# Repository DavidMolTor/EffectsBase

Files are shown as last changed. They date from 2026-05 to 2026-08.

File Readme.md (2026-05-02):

# EFFECTS BASE

Guitar effects platform for interfacing with mini PCIe based boards.

## Introduction

This project consists of a platform with all the controls and signal management for mini PCIe board-based guitar effects.

The platform contains a total of 4 potentiometers and 4 SPDT switches that are accessible throught he mini PCIe connector.

For powering, it offers high filtering and a charge pump in order to produce a negative supply rail.

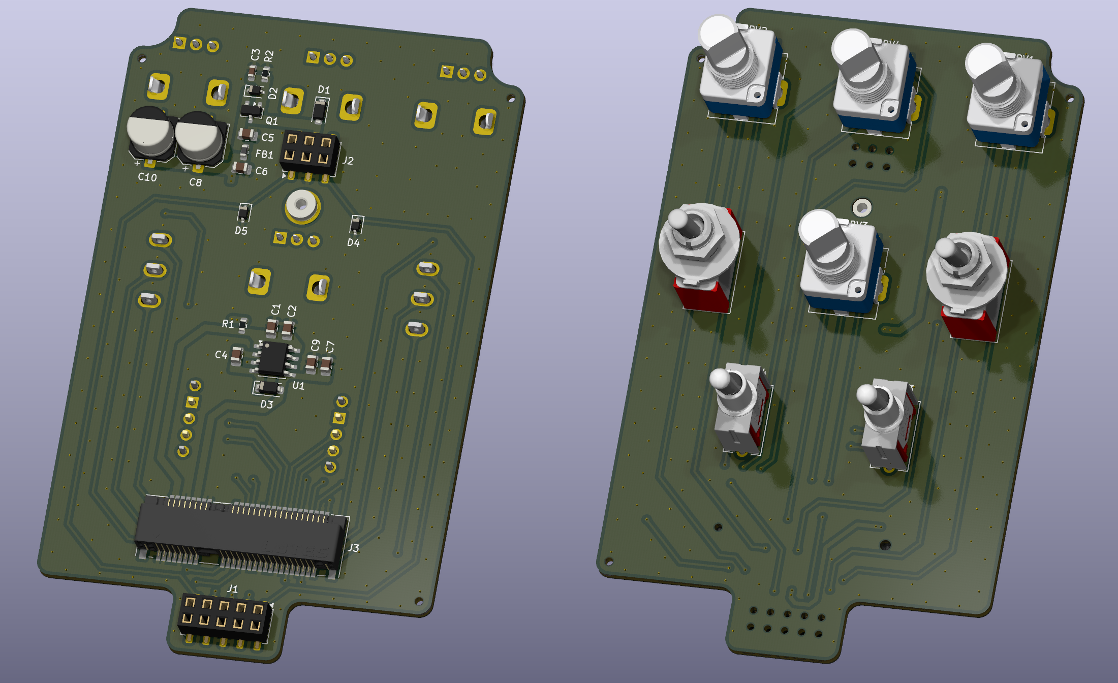
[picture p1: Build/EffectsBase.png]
EFFECTS BASE


## Features

 - Mini PCIe connector

- Charge pump inverter

 - 4 potentiometers

 - 4 SPDT switches

 - True bypass

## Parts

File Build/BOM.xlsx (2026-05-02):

Reference | Value | Footprint | Qty | Manufacturer Part | JLCPCB Part
C1,C2,C4,C5,C6,C7,C9 | 10u | Capacitor_SMD:C_0805_2012Metric | 7 | CL21A106KAYNNNE | C15850
C3 | 10n | Capacitor_SMD:C_0603_1608Metric | 1 | 0603B103K500NT | C57112
D1 | SMF10CA | Diode_SMD:D_SOD-123F | 1 | SMF10CA | C19077505
D2 | MMSZ5248B | Diode_SMD:D_SOD-323 | 1 | MMSZ5248BS | C22395566
D3 | B5819W | Diode_SMD:D_SOD-123 | 1 | B5819W SL | C8598
D4,D5 | H15VSD3B | Diode_SMD:D_SOD-323 | 2 | H15VSD3B | C20615814
FB1 | 850 | Inductor_SMD:L_0603_1608Metric | 1 | SDCL1608C68NJTDF | C13415
J3 | PCIE_FX | Custom_Parts:Mini PCI_Express_Pads | 1 | 91304-99-052R2 | C404126
Q1 | SI2301BDS | Package_TO_SOT_SMD:SOT-23 | 1 | SI2301CDS-T1-GE3 | C10487
R1 | 100 | Resistor_SMD:R_0603_1608Metric | 1 | 0603WAF1000T5E | C22775
R2 | 4.7K | Resistor_SMD:R_0603_1608Metric | 1 | 0603WAF4701T5E | C23162
U1 | ICL7660S | Package_SO:SOIC-8_3.9x4.9mm_P1.27mm | 1 | ICL7660SIBAZT | C7535

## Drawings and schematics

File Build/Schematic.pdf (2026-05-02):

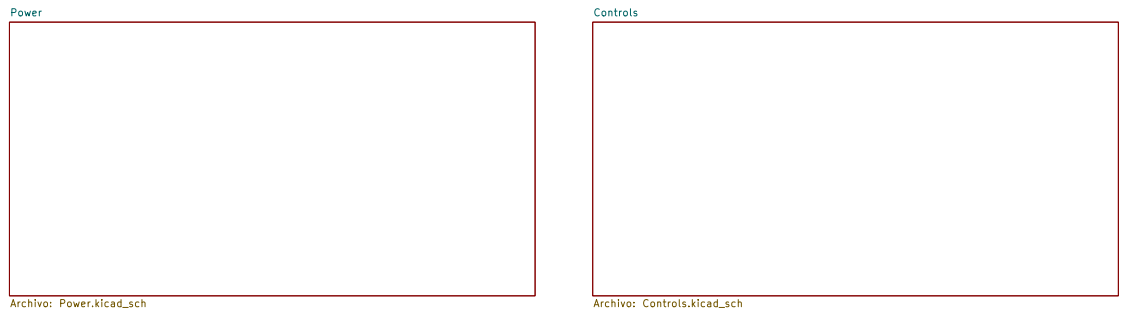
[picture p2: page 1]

Controls Archivo: Controls.kicad_sch Power Archivo: Power.kicad_sch

Size: A4 | Rev: 1.0
KiCad E.D.A. 10.0.1 | Id: 1/3

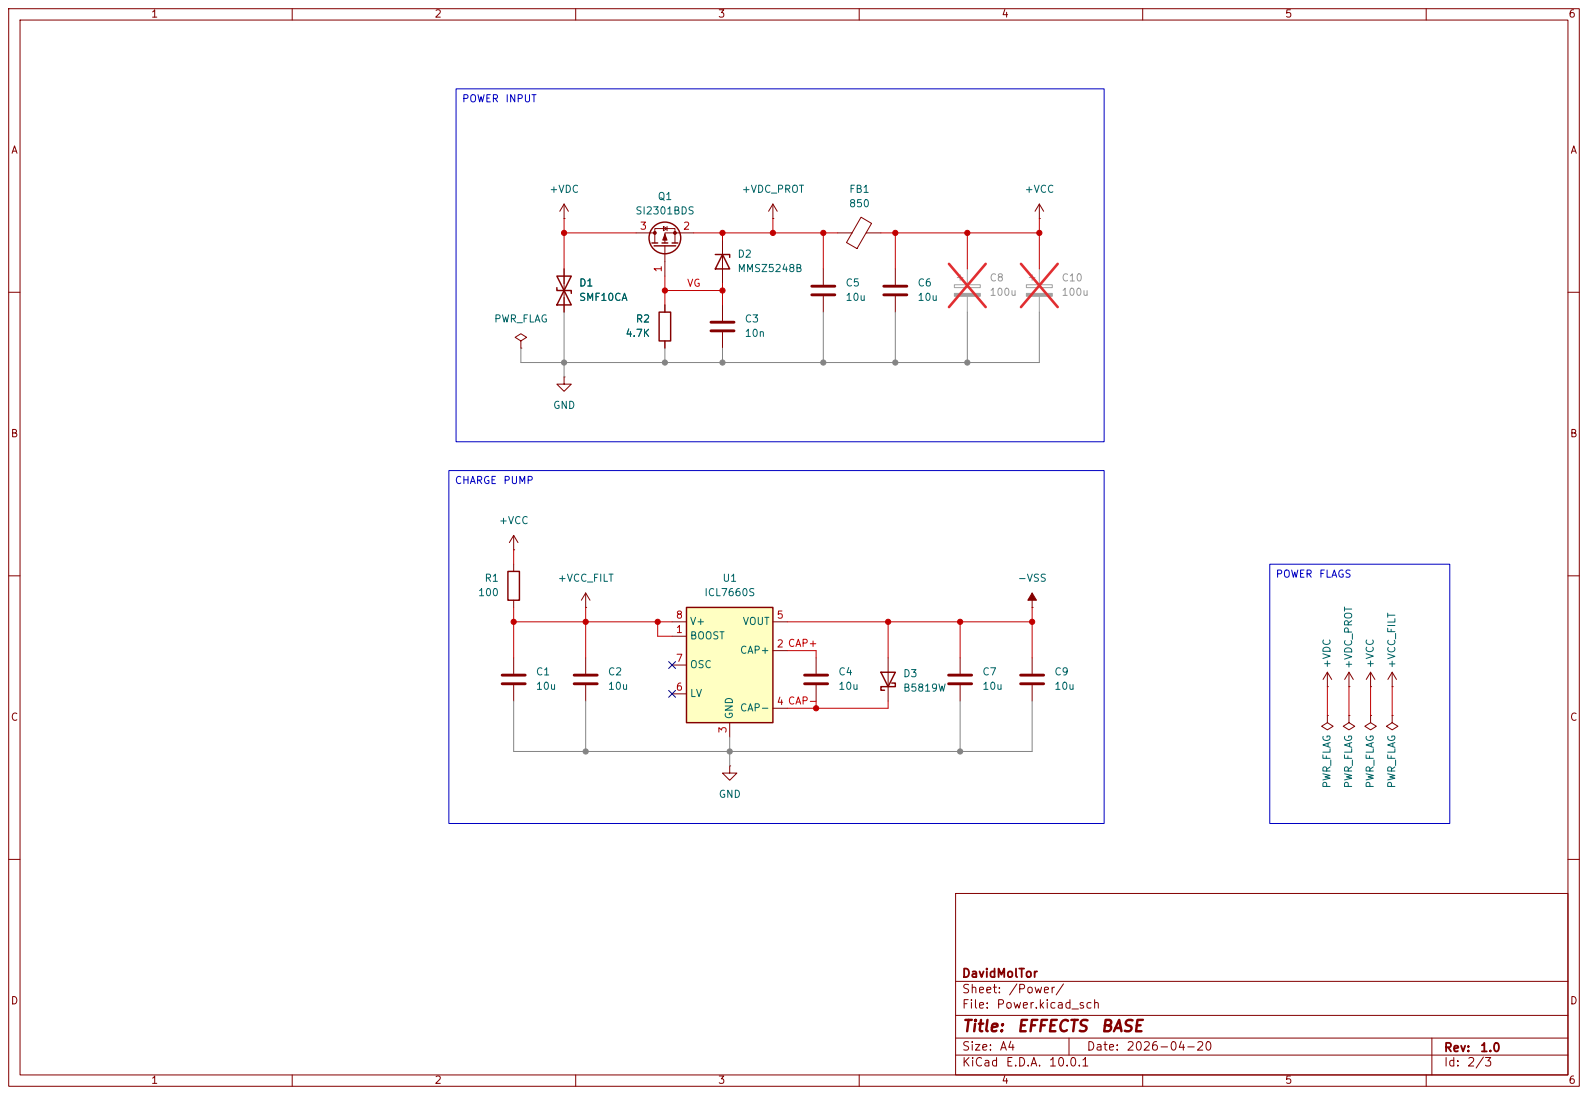
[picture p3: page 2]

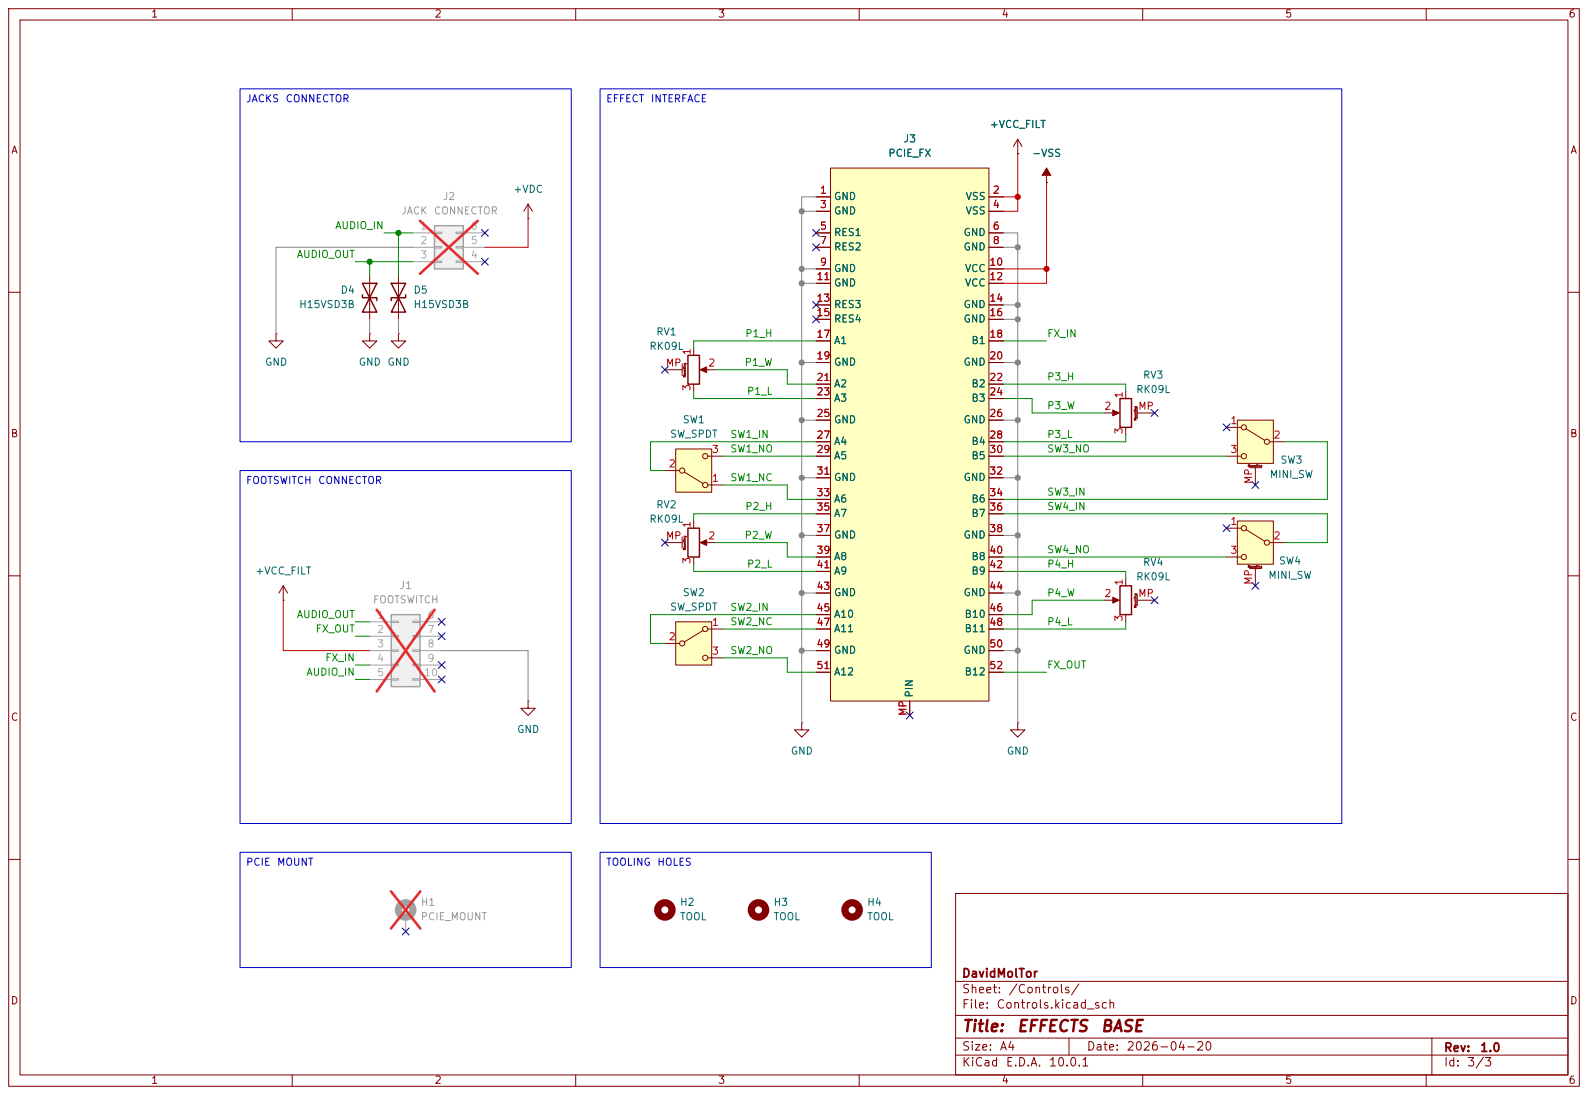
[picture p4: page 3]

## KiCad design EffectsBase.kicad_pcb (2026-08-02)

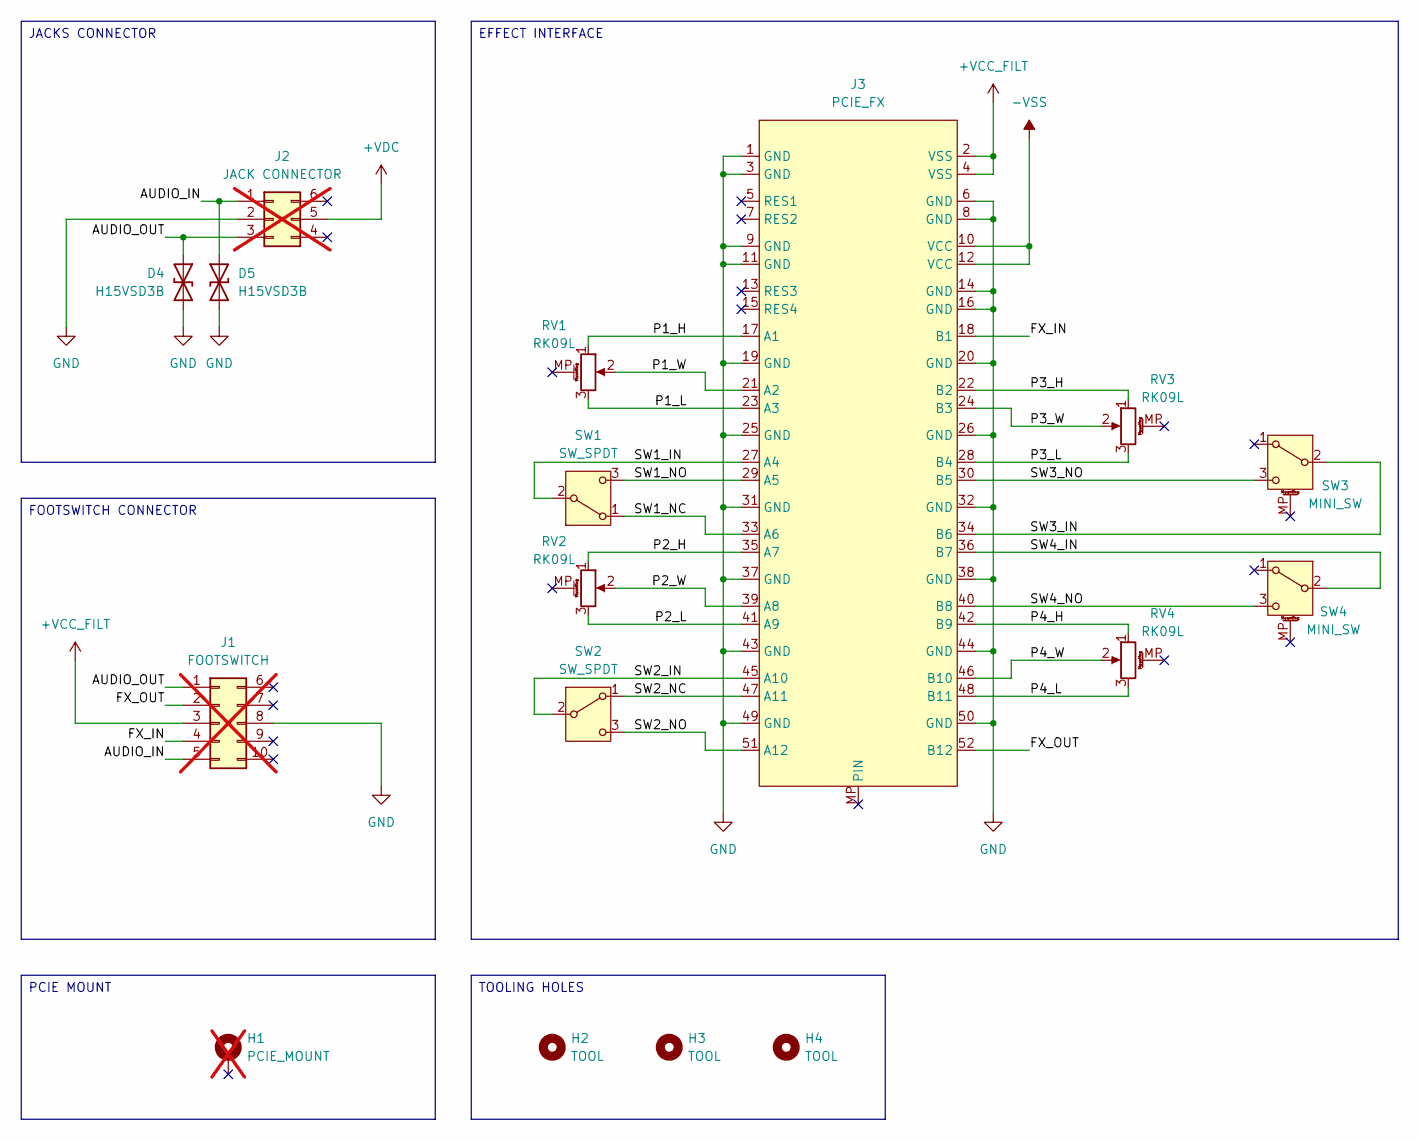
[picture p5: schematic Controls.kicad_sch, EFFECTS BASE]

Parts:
D4, D5: H15VSD3B; D_SOD-323; Manufacturer Part H15VSD3B; JLCPCB Part C20615814
H1: PCIE_MOUNT; Mounting_Wuerth_WA-SMSI-M2.5_H1.5mm_9774015151; not fitted
H2, H3, H4: TOOL; ToolingHole_1.152mm
J1: FOOTSWITCH; HEADER_THROUGH_2x05_P2.54mm; not fitted
J2: JACK CONNECTOR; HEADER_THROUGH_2x03_P2.54mm; not fitted
J3: PCIE_FX; Mini PCI_Express_Pads; Manufacturer Part 91304-99-052R2; JLCPCB Part C404126
RV1, RV2, RV3, RV4: RK09L; POT_SINGLE_VERTICAL_6X15
SW1, SW2: SW_SPDT
SW3, SW4: MINI_SW; MINI_TOGGLE_SHIELD

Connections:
+VCC_FILT: J1.3, J3.2 (VSS), J3.4 (VSS); also elsewhere on the board
+VDC: J2.5; also elsewhere on the board
-VSS: J3.10 (VCC), J3.12 (VCC); also elsewhere on the board
/Controls/AUDIO_IN: D5.1 (A1), J1.5, J2.1
/Controls/AUDIO_OUT: D4.1 (A1), J1.1, J2.3
/Controls/FX_IN: J1.4, J3.18 (B1)
/Controls/FX_OUT: J1.2, J3.52 (B12)
/Controls/P1_H: J3.17 (A1), RV1.1
/Controls/P1_L: J3.23 (A3), RV1.3
/Controls/P1_W: J3.21 (A2), RV1.2
/Controls/P2_H: J3.35 (A7), RV2.1
/Controls/P2_L: J3.41 (A9), RV2.3
/Controls/P2_W: J3.39 (A8), RV2.2
/Controls/P3_H: J3.22 (B2), RV3.1
/Controls/P3_L: J3.28 (B4), RV3.3
/Controls/P3_W: J3.24 (B3), RV3.2
/Controls/P4_H: J3.42 (B9), RV4.1
/Controls/P4_L: J3.48 (B11), RV4.3
/Controls/P4_W: J3.46 (B10), RV4.2
/Controls/SW1_IN: J3.27 (A4), SW1.2 (B)
/Controls/SW1_NC: J3.33 (A6), SW1.1 (A)
/Controls/SW1_NO: J3.29 (A5), SW1.3 (C)
/Controls/SW2_IN: J3.45 (A10), SW2.2 (B)
/Controls/SW2_NC: J3.47 (A11), SW2.1 (A)
/Controls/SW2_NO: J3.51 (A12), SW2.3 (C)
/Controls/SW3_IN: J3.34 (B6), SW3.2 (B)
/Controls/SW3_NO: J3.30 (B5), SW3.3 (C)
/Controls/SW4_IN: J3.36 (B7), SW4.2 (B)
/Controls/SW4_NO: J3.40 (B8), SW4.3 (C)
GND: D4.2 (A2), D5.2 (A2), J1.8, J2.2, J3.1 (GND), J3.3 (GND), J3.6 (GND), J3.8 (GND), J3.9 (GND), J3.11 (GND), J3.14 (GND), J3.16 (GND), J3.19 (GND), J3.20 (GND), J3.25 (GND), J3.26 (GND), J3.31 (GND), J3.32 (GND), J3.37 (GND), J3.38 (GND), J3.43 (GND), J3.44 (GND), J3.49 (GND), J3.50 (GND); also elsewhere on the board

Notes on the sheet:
TOOLING HOLES
FOOTSWITCH CONNECTOR
PCIE MOUNT
EFFECT INTERFACE
JACKS CONNECTOR

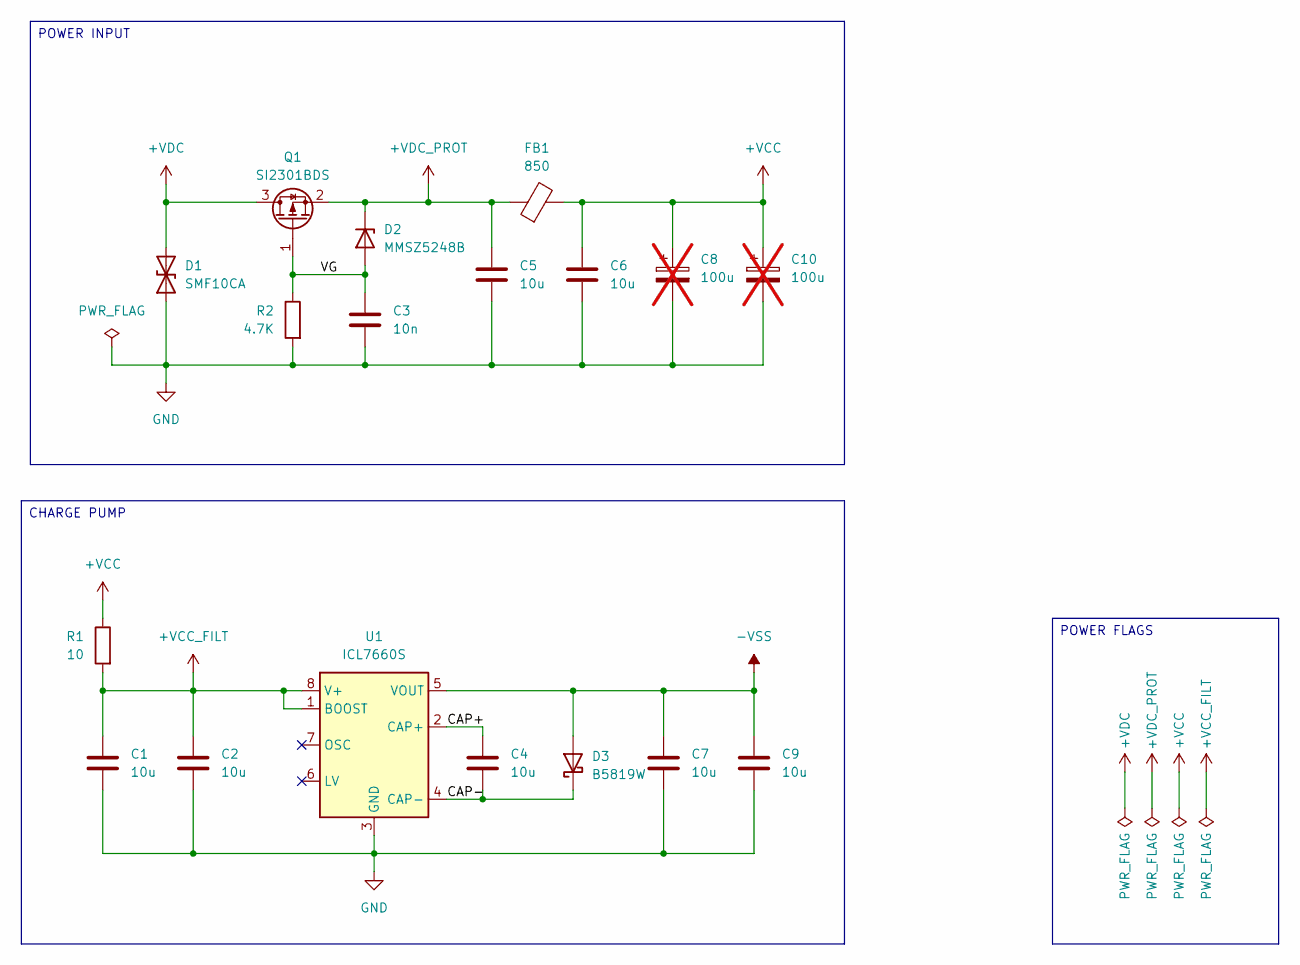
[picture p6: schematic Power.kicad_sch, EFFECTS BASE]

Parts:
C1, C2, C4, C5, C6, C7, C9: 10u; C_0805_2012Metric; Manufacturer Part CL21A106KAYNNNE; JLCPCB Part C15850
C3: 10n; C_0603_1608Metric; Manufacturer Part 0603B103K500NT; JLCPCB Part C57112
C8, C10: 100u; CP_Elec_6.3x5.8; Manufacturer Part HV1E107M0605PZ; JLCPCB Part C5246539; not fitted
D1: SMF10CA; D_SOD-123F; Manufacturer Part SMF10CA; JLCPCB Part C19077505
D2: MMSZ5248B; D_SOD-323; Manufacturer Part MMSZ5248BS; JLCPCB Part C22395566
D3: B5819W; D_SOD-123; Manufacturer Part B5819W SL; JLCPCB Part C8598
FB1: 850; L_0603_1608Metric; Manufacturer Part SDCL1608C68NJTDF; JLCPCB Part C13415
Q1: SI2301BDS; SOT-23; Manufacturer Part SI2301CDS-T1-GE3; JLCPCB Part C10487
R1: 10; R_0603_1608Metric; Manufacturer Part 0603WAF1000T5E; JLCPCB Part C22775
R2: 4.7K; R_0603_1608Metric; Manufacturer Part 0603WAF4701T5E; JLCPCB Part C23162
U1: ICL7660S; SOIC-8_3.9x4.9mm_P1.27mm; Manufacturer Part ICL7660SIBAZT; JLCPCB Part C7535

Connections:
+VCC: C6.1, C8.1, C10.1, FB1.2, R1.1
+VCC_FILT: C1.1, C2.1, R1.2, U1.1 (BOOST), U1.8 (V+); also elsewhere on the board
+VDC: D1.2 (A2), Q1.3 (D); also elsewhere on the board
+VDC_PROT: C5.1, D2.1 (K), FB1.1, Q1.2 (S)
-VSS: C7.1, C9.1, D3.2 (A), U1.5 (VOUT); also elsewhere on the board
/Power/CAP+: C4.1, U1.2 (CAP+)
/Power/CAP-: C4.2, D3.1 (K), U1.4 (CAP-)
/Power/VG: C3.1, D2.2 (A), Q1.1 (G), R2.1
GND: C1.2, C2.2, C3.2, C5.2, C6.2, C7.2, C8.2, C9.2, C10.2, D1.1 (A1), R2.2, U1.3 (GND); also elsewhere on the board

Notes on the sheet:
CHARGE PUMP
POWER INPUT
POWER FLAGS

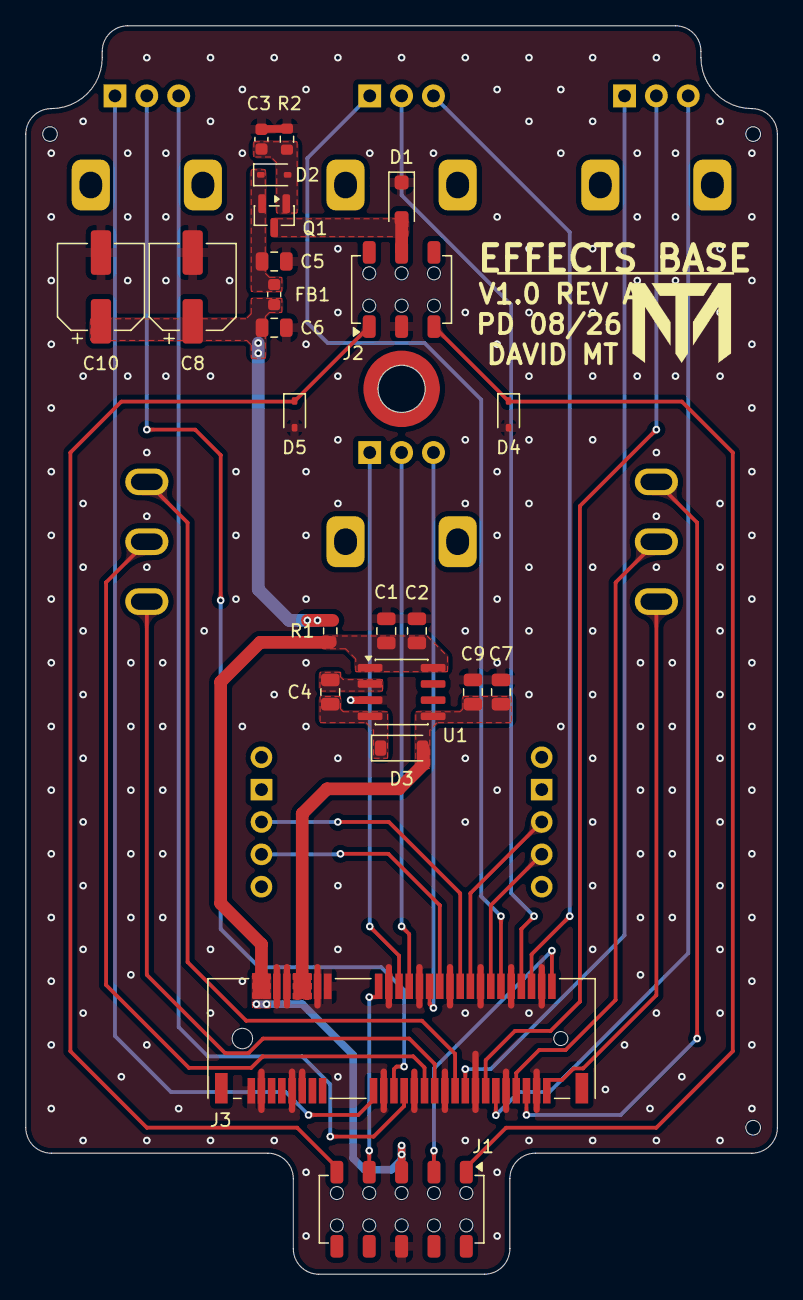
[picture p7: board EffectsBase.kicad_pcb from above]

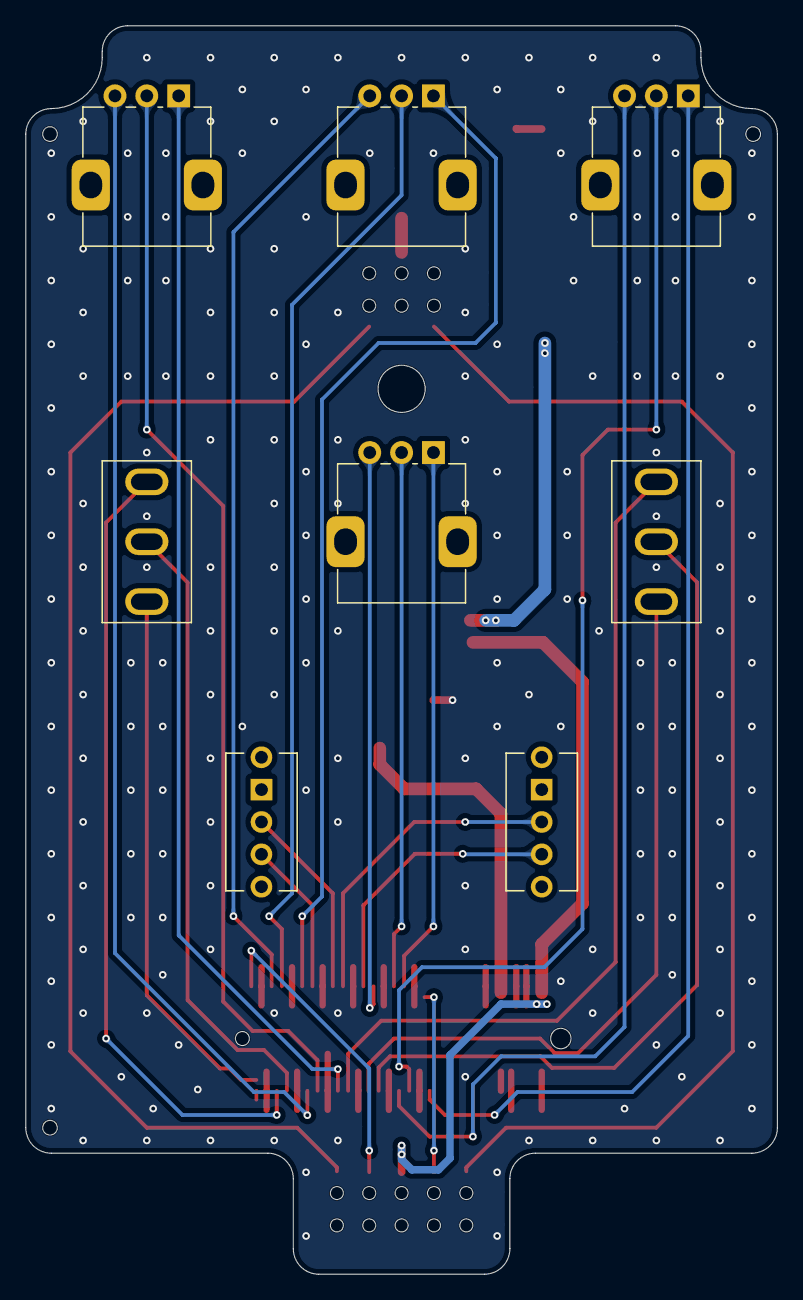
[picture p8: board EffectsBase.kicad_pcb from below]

Board: 2 copper layers, 59.0 x 98.0 mm, 35 parts (8 on the bottom side), 35 nets.

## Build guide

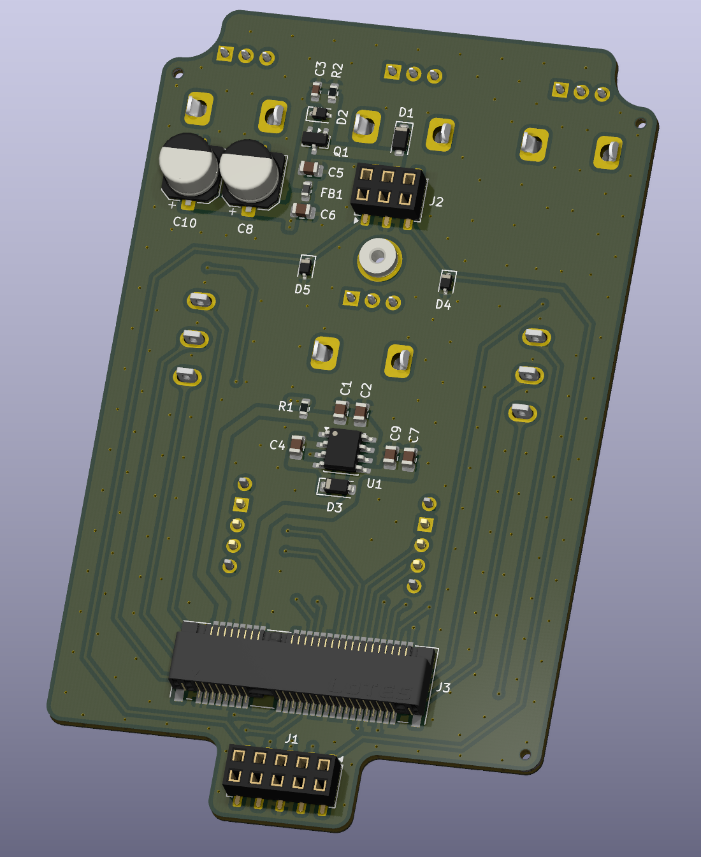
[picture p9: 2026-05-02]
Build/Front.png

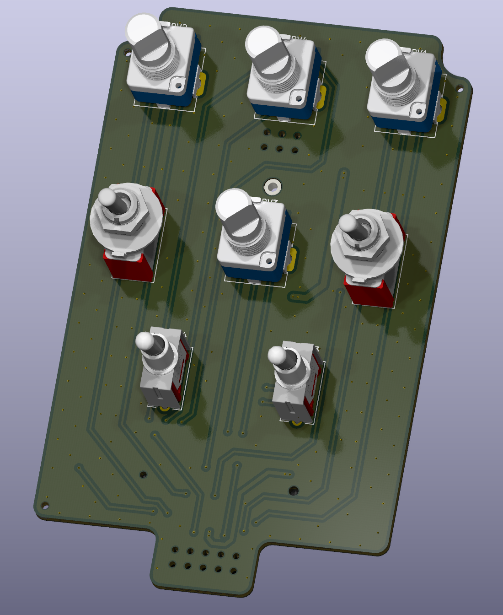
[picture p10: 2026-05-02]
Build/Back.png

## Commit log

2026-04-20 Project files
    Added the initial project files.
    [EffectsBase.kicad_pcb, EffectsBase.kicad_sch]
2026-04-22 Initial schematic
    Finished the base schematic.
    Included all the controls and updated the power supply.
    [Controls.kicad_sch, EffectsBase.kicad_pcb, EffectsBase.kicad_sch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]
2026-04-25 Initial layout
    Finished the initial PCB layout.
    [Controls.kicad_sch, EffectsBase.kicad_pcb, Power.kicad_sch]
2026-04-29 Filtering section and layout
    Updated the PCB layout.
    Added additional input voltage filtering.
    [Controls.kicad_sch, EffectsBase.kicad_pcb, Power.kicad_sch]
2026-04-29 Charge pump layout
    Added the layout for the charge pump.
    [EffectsBase.kicad_pcb]
2026-04-29 Control layout
    Updated the layout for the controls.
    [EffectsBase.kicad_pcb, Power.kicad_sch]
2026-04-30 Board layout
    Updated the layout of the power lines.
    Updated the layout of the control signals.
    [Controls.kicad_sch, EffectsBase.kicad_pcb]
2026-05-01 Layout and mounting
    Connected all tracks in the layout.
    Added a mounting standoff.
    [Controls.kicad_sch, EffectsBase.kicad_pcb]
2026-05-02 Finished layout
    Initial PCB layout iteration.
    Updated the readme file.
    Added board images.
    Added output files.
    [BOM.xlsx, Controls.kicad_sch, EffectsBase.kicad_pcb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]
2026-08-02 Minor changes
    Updated some elements in the silkscreen layer.
    Neeed to remove some components from the paste layer.
    [Controls.kicad_sch, EffectsBase.kicad_pcb, Power.kicad_sch]
